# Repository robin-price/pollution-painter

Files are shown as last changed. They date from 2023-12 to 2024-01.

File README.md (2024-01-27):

# Pollution Painter (pi 0 build)

## Overview
The Pollution Painter is a digital light painter that allows you to visualise particulate pollution levels through long exposure photography. LEDs responding to the pollution levels draw particles of light to represent particles of pollution. The effect is as if the air has been put under a microscope and lit up allowing the invisible particulates to be seen.

I built my first pollution painter in 2017 and have rebuilt, fixed and adapted it multiple times over the last seven years taking photographs of pollution levels around the world. You can [read more about the original Air of the Anthropocene project here.](https://stuffwhatidid.com/air-of-the-anthropocene)

In the interests of cutting my own pollution emissions I am now open sourcing the design and instructions in the hope that you might take these photos and collaborate with me to draw attention to pollution in your environment. Please send any photos with details of date, location and observed PM2.5 levels to robin@robinprice.net

## Design notes
The original pollution painter was built out of scraps from other projects I had lying around my studio. It used to use a single raspberry pi 0, e-ink display and WS2811 neopixel LEDs but after the delicate e-I'll displays kept breaking I moved to using the pi 0 as a WiFi access point and reading the PM2.5 data and adjusting settings with my mobile phone. The arduino got soldered into the design after an update to raspbian made the LED timings wonky and unreliable resulting in streaky photos. Off loading the code for the lights exclusively to the Arduino made things much better and makes sense given raspbian’s non real time status. Also back when I started the project I was kindly loaned an Alphasense OPC-N2 by my long time collaborator Prof. Francis Pope. This open source design uses the cheaper and widely available nova SDS011. 

I have been working on a new design built around a single raspberry pi pico and simple custom PCB that streamlines the design but this pi 0 version is presented here because you might have some of these items lying around your studio / workshop / classroom. It’s also perhaps easer to adapt or develop than the pico as you’ve a full raspbian stack with python and all its libraries as well as an Arduino to play with.

All of the designs, my original, this open source pi 0 one and the pico share the same way of working. The wrist worn sensor detects particulate PM2.5 pollution and reports this electronically to the pi. The pi records, interpolates and temporally smoothes the data a little and maps it to a value between 0 and 255. This is sent to the Arduino which uses it when visualising the data during a long exposure photograph. The Arduino very quickly loops through all the LEDS connected and randomly decides whether to turn each one briefly on based the 0 - 255 value sent from the pi. The more particles of pollution the sensor detects the higher the probability of the LEDs twinkling hence the higher particles of light in the final photograph. The calibration curve was designed for aesthetic effect and based on the readings I experienced in Delhi being the highest upper limit on the mapping scale. A trigger button wired to the pi fades the LEDs in and out during photography. I usually use a microphone boom pole to hold the LEDs up while I walk in front of the camera but this design uses a cheaper fishing rod, I invite you to find your own creative solution…

The whole device is powered from a USB battery pack with two 2.4A USB A outlets, one for the pi, sensor and Arduino and the other exclusively for the LEDs. The circuits share a common ground and the design is very much influenced by [Adafruit’s digital light painter](https://learn.adafruit.com/dotstar-pi-painter/overview), but also [Steve Mann](https://en.wikipedia.org/wiki/Steve_Mann_(inventor)) and [Timo Arnall](https://www.elasticspace.com/2013/09/the-immaterials-project).

For my original device I used three roughly two metre long strips of WS2811 30 LED per metre LED tape. These were gaffa taped together at roughly 1 cm offsets to create the illusion of a single roll of a more expensive LED tape with more LEDS. I had a ton of LED tape left lying round the studio after a previous project. This design tries to cut costs and bring it up to date with two one metre strips of 60 LED per metre Dotstar (APA 102) LEDs. I recommend taping these together so the LEDs on one strip line up with the spaces on the other to create the effect of more LEDs. I recommend getting weatherproof LEDs as sometimes it rains outdoors where you take photographs and the plastic covering doubles as a nifty light diffuser.

## BOM

| Item | Description | UK Supplier Link|
|---|---|---|
| Extensible fishing pole | I use this to fix the LED strip to sometimes with elastic bands, sometimes with bits of insulation tape | [Amazon](https://www.amazon.co.uk/dp/B017NQZZ2Q?psc=1&ref=ppx_yo2ov_dt_b_product_details) |
Pi zero W | Raspberry Pi MCU,  get one with the header socket | [Pimoroni](https://shop.pimoroni.com/products/raspberry-pi-zero-w?variant=39458414264403) |
| Dotstar LED tape | 2m strip of 60 LED / m tape doubled back on itself to make a 1m strip of 120 LED / m | [Cool Components](https://coolcomponents.co.uk/products/apa102-digital-white-addressable-led-weatherproof-strip-60-led-4m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) |
| SDS011 | Nova PM 2.5 particulate sensor | [Amazon](https://www.amazon.co.uk/DollaTek-Precision-Quality-Detection-Sensors/dp/B07M6JWCWQ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) |
| USB Battery Charger | You need a model with two 2.4A USB A outlets | [Argos](https://www.argos.co.uk/product/9215346?clickSR=slp:term:portable%20powerbank:3:65:1) |
| 18 AWG Wire | Thicker wire used for supplying current for the LEDs, doubles up for the trigger button too | [Amazon](https://www.amazon.co.uk/dp/B08F7TS37H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) |
| 26 AWG Instrument Wire | I use this to wire up the chips on the protoboard, you can use whatever wire you have handy | [Amazon](https://www.amazon.co.uk/Stranded-Electrical-Flexible-Silicone-Electric/dp/B09Y99PMRM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) |
| USB OTG cable | This connects the SDS011 to the pi's USB input | [Pi Hut](https://thepihut.com/products/usb-otg-host-cable-microb-otg-male-to-a-female) |
| Solderable USB Power connectors | Use these to make the power cable for the LEDs | [Amazon](https://www.amazon.co.uk/Connector-Adapter-Socket-Welding-Breadboard-Black/dp/B091BQW8XC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) |
| Bi-directional Level Shifter | The Arduino needs to be 5V to talk to the LEDs but the pi's logic level is 3.3V, this allows them to safely talk to each other over serial | [Pi Hut](https://thepihut.com/products/adafruit-4-channel-i2c-safe-bi-directional-logic-level-converter) |
| Pi zero perma proto board | This sits on top of the pi and has just enough space for, the Arduino and wires to connect the LEDs and the trigger | [Pi Hut](https://thepihut.com/products/adafruit-perma-proto-bonnet-mini-kit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) |
| SD card | For the pi, [an up to date disk image for the project is available here](https://drive.google.com/file/d/1RamosGUQSkOcT0gQoo1ZNAbDgKeyZLT0/view?usp=share_link) | [Amazon](https://www.amazon.co.uk/Micro-Card-MAGIX-Class10-Adapter/dp/B07LGCHSNC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) | 
| LED Strip Connectors | These are needed to make a detachable data cable to connect the Arduino as well as a power cable to connect the battery to the LEDs | [Pimoroni](https://shop.pimoroni.com/products/led-strip-input-output-cable-4-pin?variant=31374638841939) |
| Trigger Button | Any push to make button will do but this one sits nicely in the palm and gets me into trouble in airports | [Amazon](https://www.ebay.co.uk/itm/183489050436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) |
| 1m Micro USB Cable | Connects and powers the pi from the battery pack, you probably have ten lying around already | [Pi Hut](https://thepihut.com/products/usb-to-micro-usb-cable-0-5m?variant=37979679293635) | 
| Wrist strap | This is really a phone holder for runners but it provides a handy surface to hotglue electronic components to in order to make them "wearable". I invite readers to arrive at their own solutions | [Amazon](https://www.amazon.co.uk/dp/B08X7FX673?psc=1&ref=ppx_yo2ov_dt_b_product_details)|
| Arduino Pro Mini (5V version) | This programs the LEDs better than the pi can | [Cool Components](https://coolcomponents.co.uk/products/arduino-pro-mini-328-3-3v-8mhz?_pos=3&_sid=6a4299cc2&_ss=r) |

## Circuit Diagam 
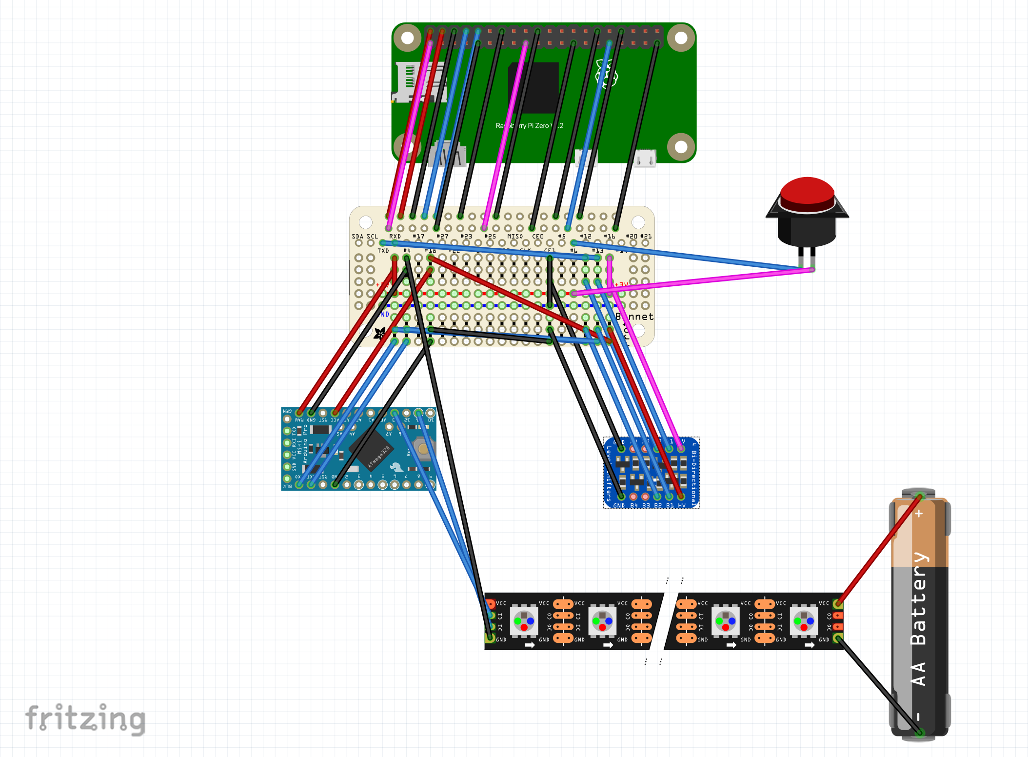
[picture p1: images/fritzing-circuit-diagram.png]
Fritzing Circuit Diagram


There's a [Fritzing available](./fritzing/pi_pollution_painter.fzz) to show how the pi, protoboard, arduino, level shifter, LEDs and trigger are wired together. Since the Fritzing library doesn't have a part for USB battery chargers I've subsituted a wholly illustrative AA battery. Notice that for similar reasons the SDS011 and pi's USB data connection to it also missing. 

## Build instructions

1. Prepare pi by soldering header strip
2. Solder Arduino and level shifter (or just header strip and tape depending how confident you feel)
3. Solder all jumper wires on perma proto board
4. Solder connector to LED data cable 
5. Make LED data and power cables
6. Solder button
7. Flash Arduino with code provided
8. Flash pi sd with this image 
9. Test and pray
10. Hot glue the contraption to the wrist strap and take some photos

## More detailed instructions

More detailed instructions are [here](./detailed-build-instructions/Pollution-Painter-Documentation-Notes.pdf) courtesy of the 'Luchtkwaliteit in Beeld' project run in Leiden with EUniwell, Margaret Gold, Carlo Luiu,Alessandro Oggioni, Francis Pope, Marin Vischer and myself. 

## How to use
If the device works when you power up the pi, after a brief boot up period, you should be able to start and stop the LEDs twinkling by pressing the trigger button. You can connect to the pi's WiFi access point from your phone and get a nubmer readout of the pollution levels (as well as a funky AR pollution viewer that negates the need for any of this fiddly long exposure photography / digital light painting).

The frontend url is  https://pollutionpainter.local

The percentage brightness of the LEDs and the ms fade in and out times can be set by typing, for example.

 https://pollutionpainter.local/api/set/brightness/70

 https://pollutionpainter.local/api/set/fade/3000

 # Key advice
 Think about timing, long exposure photography only works well at dusk, dawn and night. Plan your photography trips. Think about why you want to take a photograph at a certain place, what does recording the pollution and visualising it here say? What is the point you are trying to make with this image? Are you trying to contrast pollution levels between two places to try and point towards pollution sources? 

 When you're ready frame your image with your camera on a tripod, aim for a 10-30 second exposure and walk in front of the camera with the pollution painter. When you're in frame press the trigger once, when you think you're nearing the edge of the frame press again. Getting a good shot takes practice...

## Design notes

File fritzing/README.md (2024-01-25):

This is just a fritzing to show how I wire the arduino to the raspberry pi using a bi directional level shifter
for the serial connection in case the instructions aren't enough. It shows the LEDS too. The SDS0111 pollution 
sensor isn't in the diagram because it's connected to the pi's usb port and fritzing can't handle that. It 
also displays a AA battery for the LEDS, in reality I use a 2.4A fast charge 5V USB battery pack with two ports, 
one connected to the pi and the other the LEDS.

I've only connected the relelvant pins on the pi to the perma proto in the diagram even though in reality they're
all connected. The relevant pins are 5V, 3.3V, GND, RX/TX and GPIO BCM 6.

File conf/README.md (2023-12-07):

If installing from scratch on fresh SD do the below and be prepared to google error messages ;-) :

Install all python dependencies as root (check python / api source but flask, sds011 come to mind)

Check the conf directory for config files. Copy them to the correct places.

Copy cmdline.txt and config.txt to boot to set UART correctly (we need the 'good' UART to talk reliably to the Arduino) and enable network OTG so you can fallback access over ssh on the USB port

Install create_ap (supplied or from source) and copy create_ap.conf to /etc/ to set pi as acess point 
for reading and 'seeing' the particulate data.

Copy pollution-painter.service to /etc/systemd/system/
pollution-painter.service, check permissions, reload daemons and start / enable service to run at boot.

For webfront end install apache2

Copy conf files to /etc/apache2
Copy mycerts to /etc/ssl (needed for https so AFRAME AR will work - the first time you load page you'll have to add the cert)

Then from the project root directory copy www/html to /var/www

set your hostname to pollutionpainter

good luck!

NB if you're installing from github the project directory needs to be /home/pi/pollution_painter for the paths to work

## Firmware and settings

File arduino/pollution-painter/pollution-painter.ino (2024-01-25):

#include <FastLED.h>

#define NUM_LEDS 240
#define DATA_PIN    11
#define CLOCK_PIN   13

// Define the array of leds
CRGB leds[NUM_LEDS];

unsigned int cutoff = 250;
unsigned int brightness = 20;
unsigned int wait = 10;
unsigned int fade = 5000;
unsigned int currentBrightness;
int state = 0;

unsigned long lastUpdate;
unsigned long startTime;

const byte numChars = 32;
char receivedChars[numChars];
bool newData = false;

void setup() {
  FastLED.addLeds<DOTSTAR, DATA_PIN, CLOCK_PIN, BGR>(leds, NUM_LEDS); 
  Serial.begin(9600);
}

void recvWithStartEndMarkers() {
    static boolean recvInProgress = false;
    static byte ndx = 0;
    char startMarker = '<';
    char endMarker = '>';
    char rc;
 
    while (Serial.available() > 0 && newData == false) {
        rc = Serial.read();

        if (recvInProgress == true) {
            if (rc != endMarker) {
                receivedChars[ndx] = rc;
                ndx++;
                if (ndx >= numChars) {
                    ndx = numChars - 1;
                }
            }
            else {
                receivedChars[ndx] = '\0'; // terminate the string
                recvInProgress = false;
                ndx = 0;
                newData = true;
            }
        }

        else if (rc == startMarker) {
            recvInProgress = true;
        }
    }
}


void loop() {
  recvWithStartEndMarkers();
  if (newData) {
    //Serial.println(receivedChars);
    String inputString(receivedChars);
    Serial.print(inputString);
    if (inputString.startsWith("cutoff ") && inputString.length() == 10) {
      cutoff = constrain(inputString.substring(7).toInt(),0, 255);
//      Serial.print("cutoff ");
//      Serial.println(cutoff, DEC);
    } else if (inputString.startsWith("brightness ") && inputString.length() == 14) {
      brightness = constrain(inputString.substring(11).toInt(), 0, 255);
      FastLED.setBrightness(brightness);
//      Serial.print("brightness ");
//      Serial.println(brightness, DEC);
    } else if (inputString.startsWith("wait ") && inputString.length() == 8) {
      wait = inputString.substring(5).toInt();
//      Serial.print("wait ");
//      Serial.println(wait, DEC);
    } else if (inputString.startsWith("fade ") && inputString.length() == 9) {
      fade = inputString.substring(5).toInt();
//      Serial.print("fade ");
//      Serial.println(fade, DEC);
    } else if (inputString.startsWith("start")) {
      state = 1;
      startTime = millis();
//      Serial.println("starting");
    } else if (inputString.startsWith("stop")) {
      state = 3;
      startTime = millis();
//      Serial.println("stopping");
    }
    newData = false;
  }

  if (millis() - lastUpdate > wait) {
    switch (state) {
      case 0:
        for (int i = 0; i < NUM_LEDS; i++) {
          leds[i] = CRGB::Black;
        }
        break;
      case 1:
        if (millis() - startTime < fade) {
          for (int i = 0; i < NUM_LEDS; i++) {
            if (cutoff < random(256)) {
              leds[i] = CRGB::White;
            } else {
              leds[i] = CRGB::Black;
            }
          }
          currentBrightness = map(millis() - startTime, 0, fade, 0, brightness);
          FastLED.setBrightness(currentBrightness);
        } else {
          for (int i = 0; i < NUM_LEDS; i++) {
            if (cutoff < random(256)) {
              leds[i] = CRGB::White;
            } else {
              leds[i] = CRGB::Black;
            }
          }
          currentBrightness = brightness;
          FastLED.setBrightness(currentBrightness);
          state = 2;
        }
        break;
      case 2:
        for (int i = 0; i < NUM_LEDS; i++) {
          if (cutoff < random(256)) {
            leds[i] = CRGB::White;
          } else {
            leds[i] = CRGB::Black;
          }
        }
        break;
      case 3:
        if (millis() - startTime < fade) {
          for (int i = 0; i < NUM_LEDS; i++) {
            if (cutoff < random(256)) {
              leds[i] = CRGB::White;
            } else {
              leds[i] = CRGB::Black;
            }
          }
          currentBrightness = map(millis() - startTime, 0, fade, currentBrightness, 0);
          FastLED.setBrightness(currentBrightness);
          //strip.setBrightness(map(millis() - startTime, 0, fade, currentBrightness, 0));
        } else {
          for (int i = 0; i < NUM_LEDS; i++) {
            leds[i] = CRGB::Black;
          }
          FastLED.setBrightness(0);
          state = 0;
        }
        break;
    }
    FastLED.show();
    lastUpdate = millis();
  }
}

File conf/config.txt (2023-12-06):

# For more options and information see
# http://rpf.io/configtxt
# Some settings may impact device functionality. See link above for details

# uncomment if you get no picture on HDMI for a default "safe" mode
#hdmi_safe=1

# uncomment the following to adjust overscan. Use positive numbers if console
# goes off screen, and negative if there is too much border
#overscan_left=16
#overscan_right=16
#overscan_top=16
#overscan_bottom=16

# uncomment to force a console size. By default it will be display's size minus
# overscan.
#framebuffer_width=1280
#framebuffer_height=720

# uncomment if hdmi display is not detected and composite is being output
#hdmi_force_hotplug=1

# uncomment to force a specific HDMI mode (this will force VGA)
#hdmi_group=1
#hdmi_mode=1

# uncomment to force a HDMI mode rather than DVI. This can make audio work in
# DMT (computer monitor) modes
#hdmi_drive=2

# uncomment to increase signal to HDMI, if you have interference, blanking, or
# no display
#config_hdmi_boost=4

# uncomment for composite PAL
#sdtv_mode=2

#uncomment to overclock the arm. 700 MHz is the default.
#arm_freq=800

# Uncomment some or all of these to enable the optional hardware interfaces
#dtparam=i2c_arm=on
#dtparam=i2s=on
#dtparam=spi=on

# Uncomment this to enable infrared communication.
#dtoverlay=gpio-ir,gpio_pin=17
#dtoverlay=gpio-ir-tx,gpio_pin=18

# Additional overlays and parameters are documented /boot/overlays/README

# Enable audio (loads snd_bcm2835)
dtparam=audio=on

# Automatically load overlays for detected cameras
camera_auto_detect=1

# Automatically load overlays for detected DSI displays
display_auto_detect=1

# Enable DRM VC4 V3D driver
dtoverlay=vc4-kms-v3d
max_framebuffers=2

# Disable compensation for displays with overscan
disable_overscan=1

[cm4]
# Enable host mode on the 2711 built-in XHCI USB controller.
# This line should be removed if the legacy DWC2 controller is required
# (e.g. for USB device mode) or if USB support is not required.
otg_mode=1

[all]

[pi4]
# Run as fast as firmware / board allows
arm_boost=1

[all]
dtoverlay=dwc2
dtoverlay=disable-bt
#dtparam=uart0=on
#dtoverlay=uart0,txd0_pin=32,rxd0_pin=33,pin_func=7
enable_uart=1

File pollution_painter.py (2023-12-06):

#!/usr/bin/python
#POLLUTION PAINTER - 'MAKING THE INVISIBLE VISIBLE' SINCE 2017!
#ROBIN PRICE 2017-2023

import time, os, sys, threading, zmq, struct
import RPi.GPIO as GPIO
from sds011lib import SDS011QueryReader
from serial import Serial
from datetime import datetime
from collections import deque
from scipy import interpolate
import numpy as np
from typing import List, Any
from time import sleep

class PollutionPainter:
	trigger_switch_pin = 6
	zmq_context = None
	zmq_socket = None
	got_brightness = False
	brightness = 30
	got_wait = False
	wait = 10
	got_fade = False
	fade = 1000
	sensor = None
	arduino_port = None
	sending_to_arduino = False
	currently_drawing = False
	just_started = False
	just_stopped = False
	dummy_mode = False
	dummy_pm25 = 0

	pm25 = 0
	buff = deque(np.zeros(5, dtype='f'), 5)
	tbuff = deque(np.zeros(5, dtype='f'), 5)
	x_points = np.linspace(0,550, num=256, endpoint=False)
	y_points = np.linspace(255,45, num=256, endpoint=False)

	def __init__(self):
		try:
			#TRIGGER BUTTON SETUP
			GPIO.setmode(GPIO.BCM)
			GPIO.setup(self.trigger_switch_pin, GPIO.IN,  pull_up_down=GPIO.PUD_DOWN)
			GPIO.add_event_detect(self.trigger_switch_pin, GPIO.FALLING, callback=self.trigger_callback, bouncetime=1000)

			#SENSOR SETUP
			self.sensor = SDS011QueryReader('/dev/ttyUSB0')

			#ARDUINO SERIAL LINK SETUP
			self.arduino_port = Serial("/dev/ttyAMA0", baudrate=9600, bytesize=8, parity='N', stopbits=1, timeout=0)

		except Exception as e:
			print ("Startup Error: {}".format(e))

	def run(self):
		try:
			#START SAMPLING
			self.sample()
			
			#START TALKING TO LED
			self.control_LEDS()
			
			#HANDLE WEB FRONT END
			self.handle_zmq()

		except:
			GPIO.cleanup()

	def trigger_callback(self,arg):
		print("button {} pressed".format(str(self.trigger_switch_pin)))
		if self.currently_drawing:
			self.currently_drawing = False
			self.just_stopped = True
		else:
			self.currently_drawing = True
			self.just_started = True

	def sample(self):
		threading.Timer(1.0, self.sample).start()
		aqi = self.sensor.query()
		if (aqi.pm25):
			print("PM2.5 " + str(aqi.pm25) + " ug/m^3")
			self.pm25 = aqi.pm25
			self.tbuff.append(time.time())
			self.buff.append(aqi.pm25)

	def control_LEDS(self):
		threading.Timer(1.0, self.control_LEDS).start()
		if not self.sending_to_arduino:
			if self.just_started:
				self.command_out("<start>")
				self.just_started = False
			if self.just_stopped:
				self.command_out("<stop>")
				self.just_stopped = False
			if self.got_brightness:
				self.command_out("<brightness " + str(self.brightness).zfill(3) + ">")
				self.got_brightness = False
			if self.got_wait:
				self.command_out("<wait " + str(self.wait).zfill(3) + ">")
				self.got_wait = False
			if self.got_fade:
				self.command_out("<fade " + str(self.fade).zfill(4) + ">")
				self.got_fade = False

			interpolated_pm25 = (self.f(time.time() - 1, self.buff, self.tbuff))
			print("interpolated_pm25 = {}".format(interpolated_pm25))
			if (self.dummy_mode == True):
				interpolated_PM25 = self.dummy_pm25
			cutoff=int(np.interp(interpolated_pm25, self.x_points, self.y_points))
			self.command_out("<cutoff " + str(cutoff).zfill(3) + ">")
		else:
			print("already sending")

	def command_out(self, command):
		self.sending_to_arduino = True
		correct_response = False
		attempts = 0
		while correct_response == False and attempts < 8:
			print("sending " + command)
			self.arduino_port.flushInput()
			self.arduino_port.flushOutput()
			bytes_out = self.arduino_port.write(command.encode('utf-8'))
			attempts = attempts + 1
			sleep(0.1)
			response = "<" + self.arduino_port.read(bytes_out).decode('utf-8') + ">"
			print("got response " + response)
			if response == command:
				correct_response = True
		if not correct_response:
			print("failed to send {} to arduino".format(command))
		self.sending_to_arduino = False

	def handle_zmq(self):		
		#LISTEN FOR ZMQ FROM WYSGI TO SERVE WEB FRONT END
		self.zmq_context = zmq.Context()
		self.zmq_socket = self.zmq_context.socket(zmq.REP)
		self.zmq_socket.bind("tcp://*:5555")
		while True:
			try:
				message = self.zmq_socket.recv_multipart()
				if (message[0] == b'get_pm25'):
					print("get_pm25 request sending pm25 = {}".format(str(self.pm25)))
					ba = bytearray(struct.pack("f", self.pm25))
					self.zmq_socket.send(ba)
				elif (message[0] == b'set_brightness'):
					self.brightness = struct.unpack('i', message[1])[0]
					print("set_brightness request setting brightness = {}".format(str(self.brightness)))
					self.zmq_socket.send(b'msg_rxd')
					self.got_brightness = True
				elif (message[0] == b'set_fade'):
					self.fade = struct.unpack('i', message[1])[0]
					print("set_fade request setting fade = {}".format(str(self.fade)))
					self.zmq_socket.send(b'msg_rxd')
					self.got_fade = True
				elif (message[0] == b'set_refresh'):
					self.wait = struct.unpack('i', message[1])[0]
					print("set_refresh request setting wait = {}".format(str(self.wait)))
					self.zmq_socket.send(b'msg_rxd')
					self.got_wait = True
			except Exception as err:
				print(Exception, err)
				print("error in zmq request")

	def f(self, x, b, t):
		y_points = np.array(list(b))
		x_points = np.array(list(t))
		return np.interp(x, x_points, y_points)

if __name__ == '__main__':
	user = os.getuid()
	if user != 0:
		print("Please run script as root")
		sys.exit()

	painter = PollutionPainter()
	painter.run()

#CODE BELOW IS LEGACY REMINDER CODE 


def manualmode_handler(address: str, *args: List[Any]) -> None:
	print(address)
	print(args)
	print(len(args))
	print(type(args[0]))
	print(type(args[1]))
	if not len(args)== 1 or type(args[0]) is not float:
		global DUMMY_MODE
		if args[1] == 1:
			DUMMY_MODE = True
			print("set DUMMY_MODE = True")
		else:
			DUMMY_MODE = False
			print("set DUMMY_MODE = False")

def manualPM25_handler(address: str, *args: List[Any]) -> None:
	if not len(args)== 1 or type(args[0]) is not float:
		global DUMMY_PM25
		DUMMY_PM25 = int(args[1])
		print("recieved OSC /manualPM25 {}".format(DUMMY_PM25))
		client.send_message("/manualPM25", DUMMY_PM25)

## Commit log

2024-01-25 added arduino code
2024-01-25 added fritzing diagram
    [pi_pollution_painter.fzz]
